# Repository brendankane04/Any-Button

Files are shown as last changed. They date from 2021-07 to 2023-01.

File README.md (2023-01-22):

# Any Button
With this device, you can make any pushbutton or switch on a home appliance *remote controlled!* 

Simply connect the leads of the button of the appliance to the relay on this device, and it will make the device remote-operated.

## Materials:

1. [VS1838 IR Receiver](https://datasheetspdf.com/pdf-file/700398/ETC/VS1838B/1) <br>
2. [IR Remote (MP3 Control)](https://www.amazon.com/KOOBOOK-Infrared-Wireless-Control-Receiver/dp/B07S67SFSF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) <br>
3. [Attiny85, DIP package](https://www.amazon.com/Original-Atmel-Dip-8-ATTINY85-20PU-Tiny85-20Pu/dp/B06W9JBJJ6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) <br>
4. [L7805 5V Voltage regulator](https://www.amazon.com/Pieces-Voltage-Regulator-Linear-Positive/dp/B07RB251DC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) <br>
5. Various Electical Components <br> 

## Firmware: 

This file system is a project which can be conveniently opened in Atmel Studio 7 with the following important source files:

### Files:

-**main.cpp:** Main file<br>
-**IR_Receiver.cpp:** Driver for the IR Receiver connected to the INT0 pin. It receives IR commands based on the IR-NEC protocol<br>
-**Relay.cpp:** Driver for the relay which simulates the switch or button<br>
-**Lever.cpp:** Driver for a relay which controls a solenoid attached to a lever. This requires more physical set up & hardware but doesn't necessitate directly wiring to the appliance.<br>
-**BB\_I2C.cpp:** Driver for a rudimentary pseudo-I2C communication protocol. It was written to make debugging easier.<br>

## Schematics:

This file system contains a project which builds the schematic design & the board layout of the device. 
The project can opened with kicad.

The device may be connected to the appliance by attaching a >= 5V line or by using an independent voltage source.

It uses default parts & layouts. Consequently, it has no custom libraries.

The final product can be conveniently viewed in the form of PDF's

### PDF's:

-**Schematic.pdf:** Image of the schematics <br>
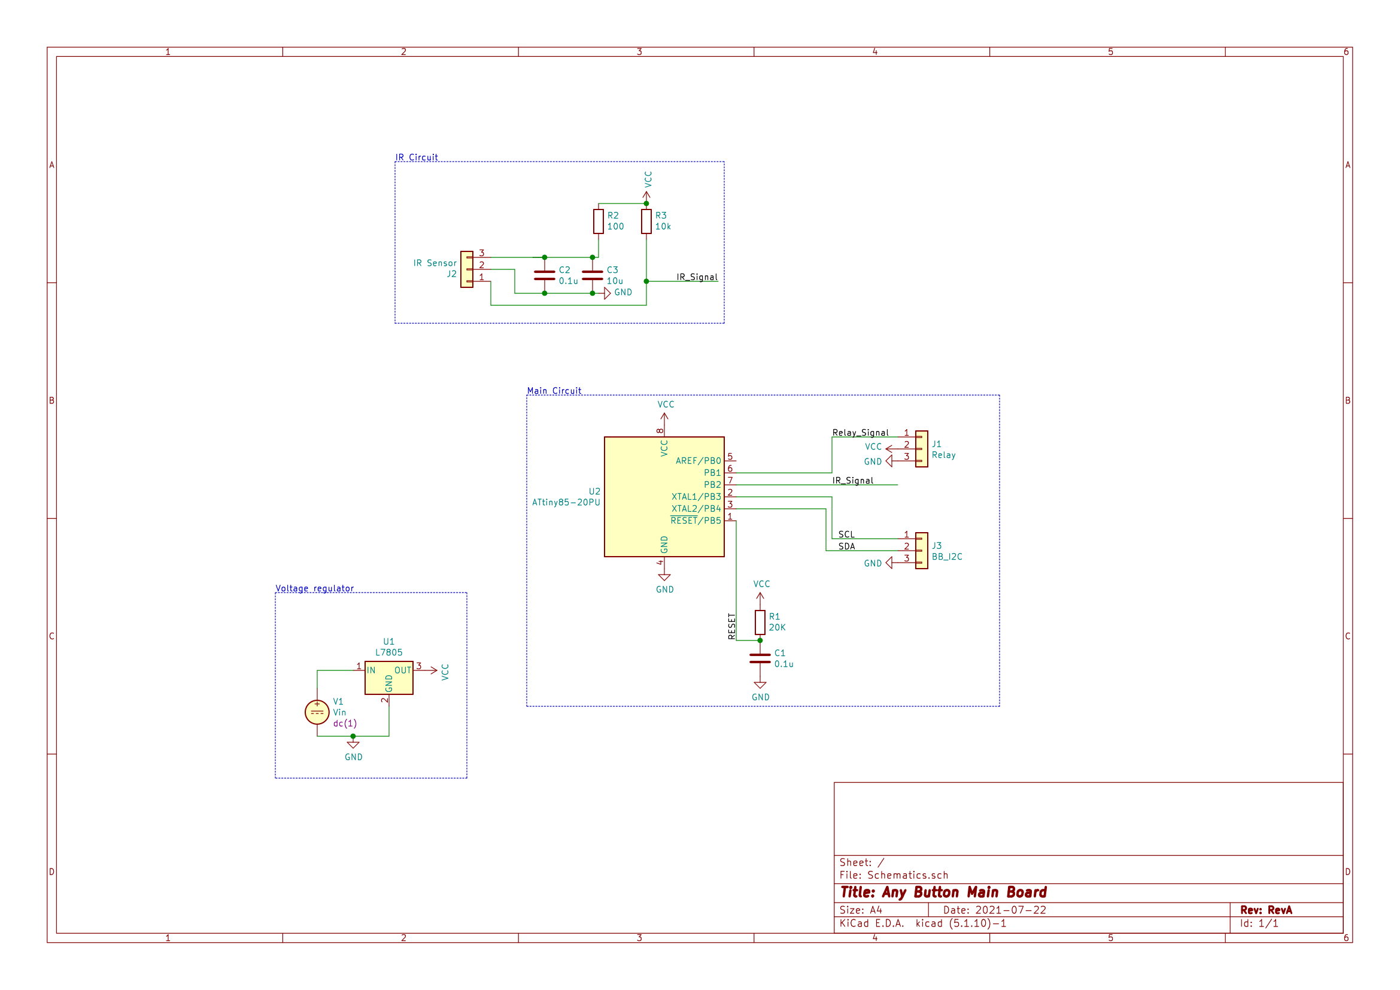
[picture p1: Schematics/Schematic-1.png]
Schematics
<br>
-**Layout.pdf:** Image of the board layout <br>
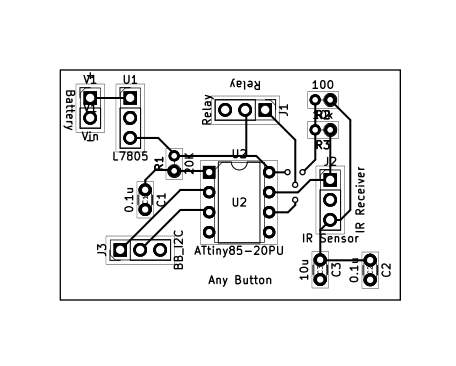
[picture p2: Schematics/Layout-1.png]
Layout
<br>

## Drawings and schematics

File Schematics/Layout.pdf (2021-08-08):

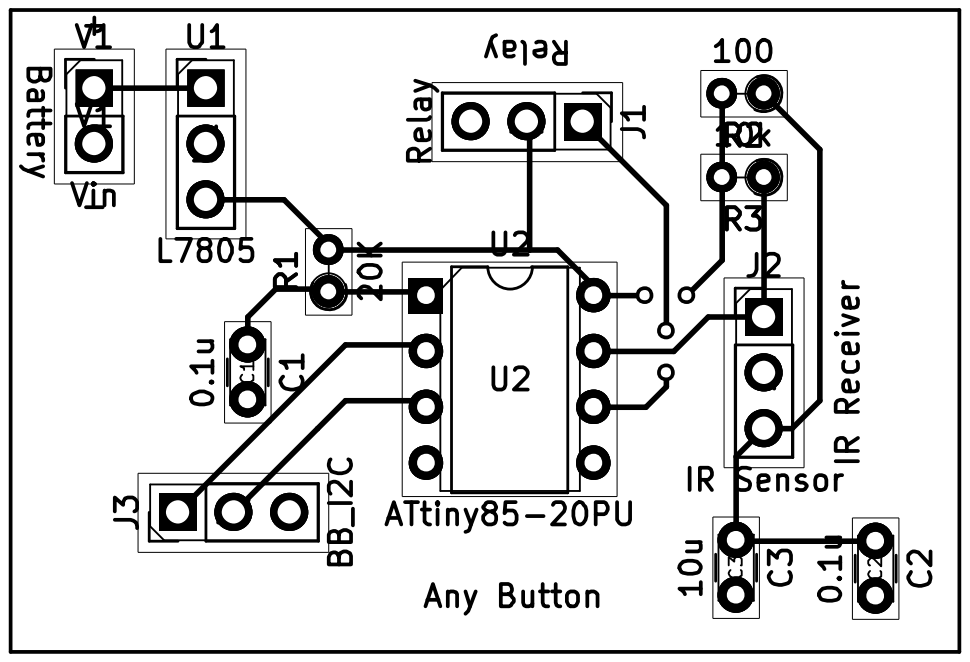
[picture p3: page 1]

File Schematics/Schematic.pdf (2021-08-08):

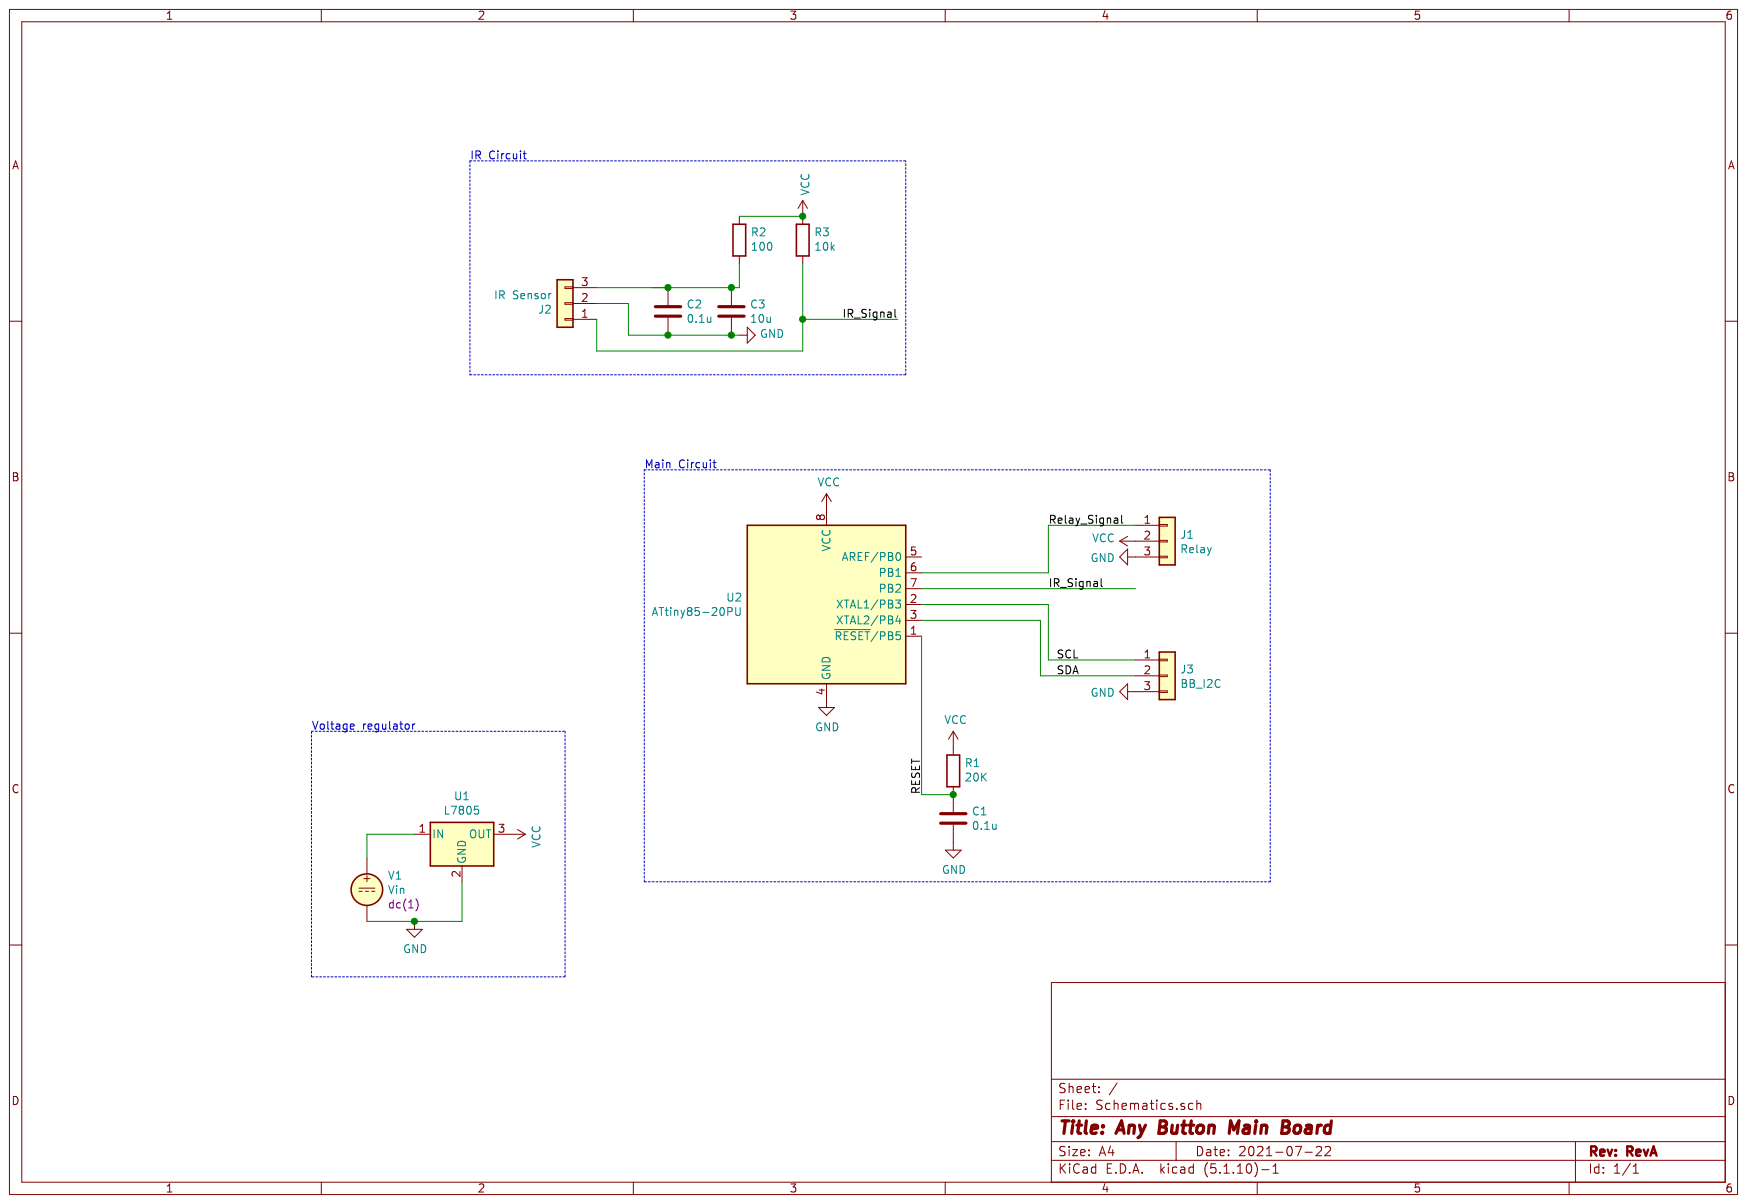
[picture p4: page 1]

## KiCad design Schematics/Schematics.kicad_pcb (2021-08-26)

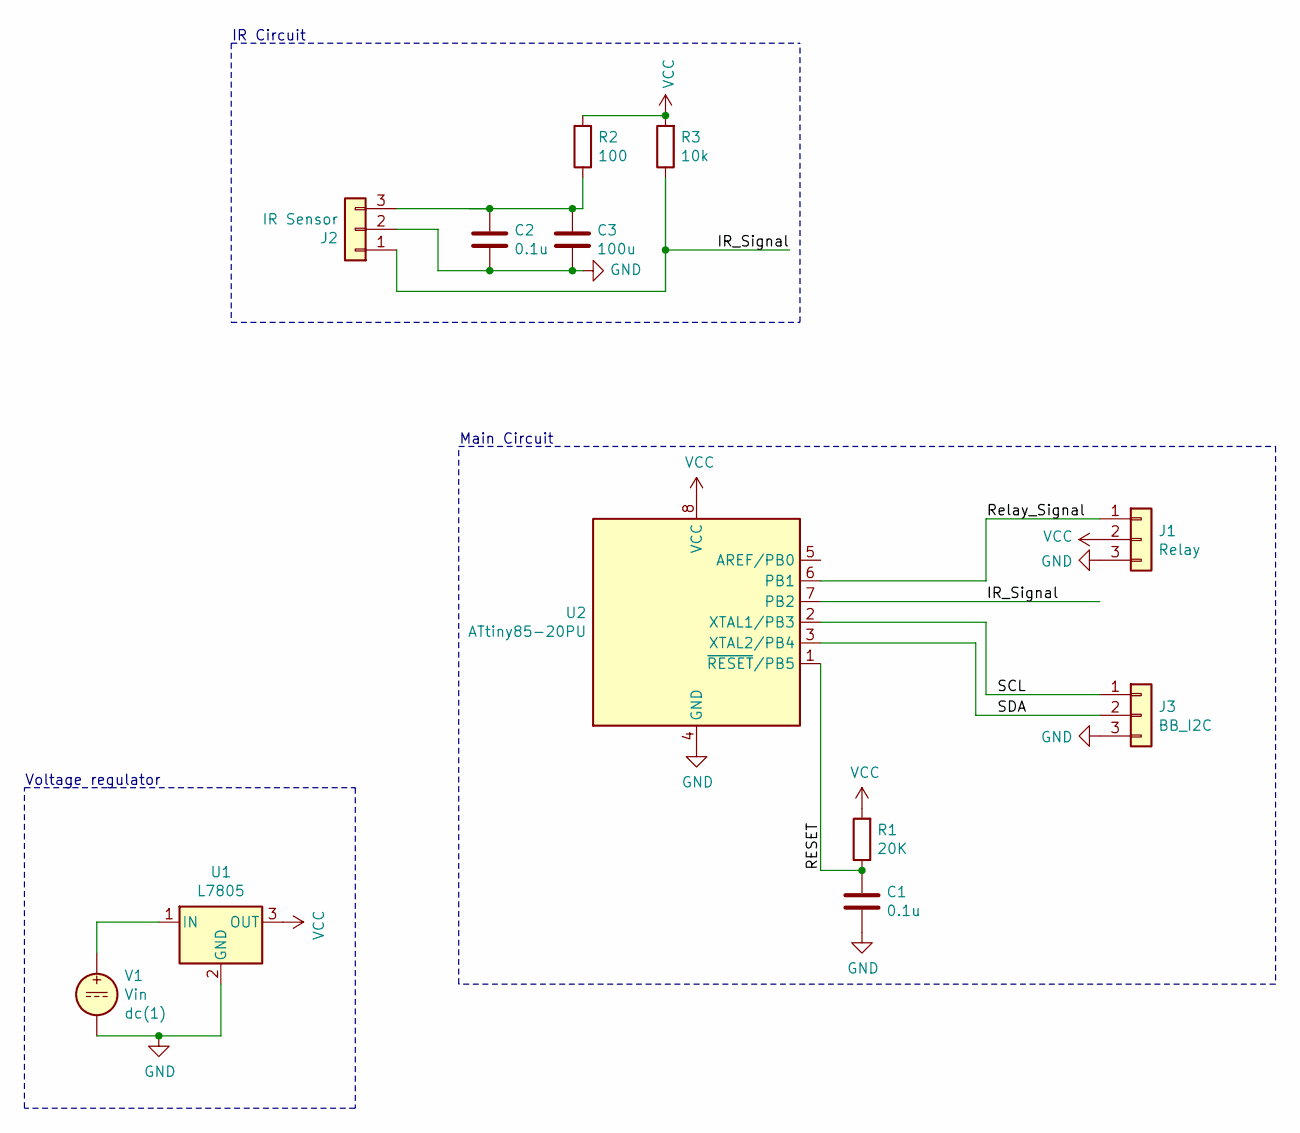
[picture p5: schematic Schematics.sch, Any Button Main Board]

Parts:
C1, C2: 0.1u; C_Disc_D3.0mm_W1.6mm_P2.50mm
C3: 100u; C_Disc_D3.0mm_W1.6mm_P2.50mm
J1: Relay; PinHeader_1x03_P2.54mm_Vertical
J2: IR Sensor; PinHeader_1x03_P2.54mm_Vertical
J3: BB_I2C; PinHeader_1x03_P2.54mm_Vertical
R1: 20K; R_Axial_DIN0204_L3.6mm_D1.6mm_P1.90mm_Vertical
R2: 100; R_Axial_DIN0204_L3.6mm_D1.6mm_P1.90mm_Vertical
R3: 10k; R_Axial_DIN0204_L3.6mm_D1.6mm_P1.90mm_Vertical
U1: L7805; PinHeader_1x03_P2.54mm_Vertical
U2: ATtiny85-20PU; DIP-8_W7.62mm
V1: Vin; PinHeader_1x02_P2.54mm_Vertical

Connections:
/IR_Signal: J2.1, R3.1, U2.7 (PB2)
/RESET: C1.1, R1.1, U2.1 (~RESET~/PB5)
/Relay_Signal: J1.1, U2.6 (PB1)
/SCL: J3.1, U2.2 (XTAL1/PB3)
/SDA: J3.2, U2.3 (XTAL2/PB4)
GND: C1.2, C2.2, C3.2, J1.3, J2.2, J3.3, U1.2 (GND), U2.4 (GND), V1.2; also elsewhere on the board
unnamed: C2.1, C3.1, J2.3, R2.1
unnamed: U1.1 (IN), V1.1
VCC: J1.2, R1.2, R2.2, R3.2, U1.3 (OUT), U2.8 (VCC); also elsewhere on the board

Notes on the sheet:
Voltage regulator
Main Circuit
IR Circuit

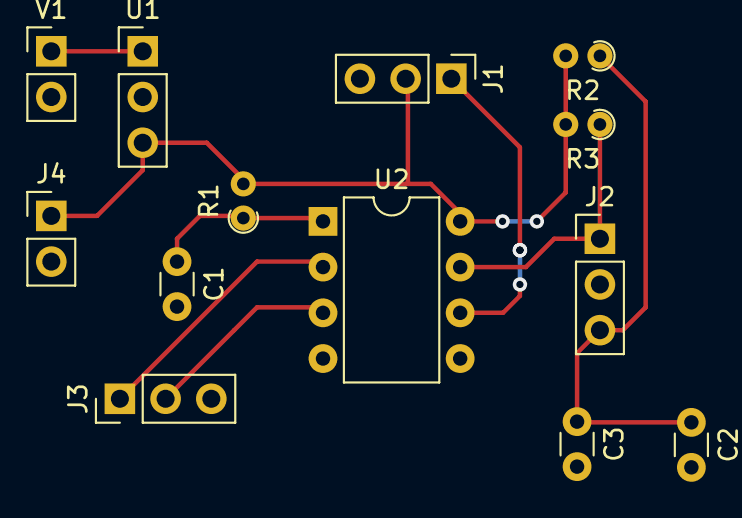
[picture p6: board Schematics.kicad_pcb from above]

Board: 2 copper layers, 13 parts (0 on the bottom side), 9 nets.

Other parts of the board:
J4: Conn_01x02; PinHeader_1x02_P2.54mm_Vertical

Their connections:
GND: J4.2; also elsewhere on the board
VCC: J4.1; also elsewhere on the board

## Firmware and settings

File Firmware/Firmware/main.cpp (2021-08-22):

//Remote Control Receiver Momentary+Alternate Original ATtiny13A 20191021 2200
//PB1,PB2 : Momentary Operation
//PB3,PB4 : Alternate Operation

#ifndef F_CPU
#define F_CPU 8000000UL
#endif 

#include <avr/io.h>
#include <avr/interrupt.h>
#include <util/delay.h>
#include "IR_Receiver.h"
#include "Relay.h"

#define FALSE 0
#define TRUE  1

int main(void)
{
	IR_Receiver sensor1(7);
	Relay button1(1);

	//Initialize an empty IR command
	IR_Receiver::IR_cmd remote_cmd;

	while(1)
	{
		remote_cmd = sensor1.recv();
		switch(remote_cmd.cmd)
		{
			case IR_Receiver::POWER:
				button1.press();
				break;
			case IR_Receiver::ZERO:
				button1.button_set(FALSE);
				break;
			case IR_Receiver::ONE:
				button1.button_set(TRUE);
				break;
			default:
				break;
		}
		_delay_ms(10);
	}
}

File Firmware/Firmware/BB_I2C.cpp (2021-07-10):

/* 
* BB_I2C.cpp
*
* Created: 7/7/2021 11:03:41 PM
* Author: brend
*/

#ifndef F_CPU
#define F_CPU 8000000
#endif

#include <avr/io.h>
#include <util/delay.h>
#include "BB_I2C.h"

// default constructor
BB_I2C::BB_I2C(int sda, int scl)
{
	//Set the pins which the interface is using
	this->SDA = _BV(sda);
	this->SCL = _BV(scl);

	//Set the SDA & SCL pins on PORTB as outputs
	DDRB |= SDA | SCL;

	//Set SCL to high
	PORTB |= SCL;
}

void BB_I2C::write(char data)
{
	char curr;

	//Start bit
	PORTB &= ~SCL;
	_delay_us(100);

	for(int i = 0; i < 8; i++)
	{
		//Get the current bit
		curr = (data >> (7 - i)) & 0x01;

		//Turn on the clock cycle
		PORTB |= SCL;

		//Send out the bit
		if(curr) PORTB |= SDA;
		else	 PORTB &= ~SDA;
		_delay_us(100);

		//Pull the data bit & clock cycle to low
		PORTB &= ~SCL & ~SDA;
		_delay_us(100);
	}

	//Clear data line
	PORTB &= ~SDA;
	//Start bit
	PORTB |= SCL;
}

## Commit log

2021-07-01 A function for waiting for the pin to change & recording the wait time was created from scratch.
2021-07-07 Removed bug in recv() which would cause all comparisons to fail.
    [main.cpp]
2021-07-07 A relay class was added to control the relay with toggling & sets. However, it needs to be tested.
2021-07-07 Interrupt enabling was removed.
2021-07-07 The bit-banged pseudo-I2C functionality was modularized into a BB_I2C class.
2021-07-11 Quality of life improvements for the relay code.
2021-07-14 The IR Reciever code was altered to read from any arbitrary PCINTX pin. Testing is required.
2021-07-14 The speed of the system clock was increased when attaching IR sensor.
2021-07-16 A button was made more obvious.
2021-07-16 The relay controls were moved to modularized functions in case other relays work differently.
2021-07-17 The materials section was updated.
2021-07-20 A schematics directory was created.
    [Schematics.kicad_pcb, Schematics.sch]
2021-07-22 A rudimentary schematic was created.
    [Schematics.sch]
2021-07-22 The circuitry for the reset line was added.
    [Schematics.sch]
2021-07-22 Footprints for various connectors were added,
    [Schematics.sch]
2021-07-22 The schematics were sectioned off.
    [Schematics.sch]
2021-07-22 Footprints for the voltage regulator were picked.
    [Schematics.sch]
2021-07-22 The net list was generated. It needs work though. The decoupling capcitor also needs a smaller footprint. It's about as large as the ATTINY. That's excessive.
    [Schematics.sch]
2021-07-22 The capictor's footprint was shrunk.
    [Schematics.kicad_pcb]
2021-07-22 The basic routes were finished.
    [Schematics.kicad_pcb, Schematics.sch]
2021-07-22 A silkscreen was added.
    [Schematics.kicad_pcb]
2021-07-22 A simpler cutout of the board was made.
    [Schematics.kicad_pcb]
2021-07-22 The title block was modified, and a PDF of the layout was made.
    [Schematics.sch]
2021-07-22 A PDF of the schematic was made.
2021-07-28 A class for controlling solenoids via a relay was added.
2021-08-01 The compatibility circuit for the IR Receiver was added to the schematics.
    [Schematics.sch]
2021-08-01 An error was correct, and the board was updated. Adjustments are still necessary.
    [Schematics.kicad_pcb]
2021-08-07 The IR circuit was added to the layout.
    [Schematics.kicad_pcb, Schematics.sch]
2021-08-10 The schematic was updated.
    [Schematics.kicad_pcb, Schematics.sch]
2021-08-15 Erroneous code was commented out. However, errors persist.
    [main.cpp]
2021-08-15 By fixing up the firmware & hardware, the project is back to a working state.
    [main.cpp]
2021-08-16 A capacitor value was changed.
    [Schematics.kicad_pcb, Schematics.sch]
2021-08-20 The other buttons on the remote were added.
2021-08-26 A battery input was added for lower voltages.
    [Schematics.kicad_pcb]
2021-08-27 A header was removed.
    [Schematics.sch]
